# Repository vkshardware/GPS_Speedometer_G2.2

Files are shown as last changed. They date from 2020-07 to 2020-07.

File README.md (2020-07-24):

# GPS_Speedometer_G2.2
4-digits Speedometer (+ Odometer + Altimeter + Clock) for DIY all-terrain vehicles (ATV) with PULSE output

**vksensor GPS Speedometer G2.2**

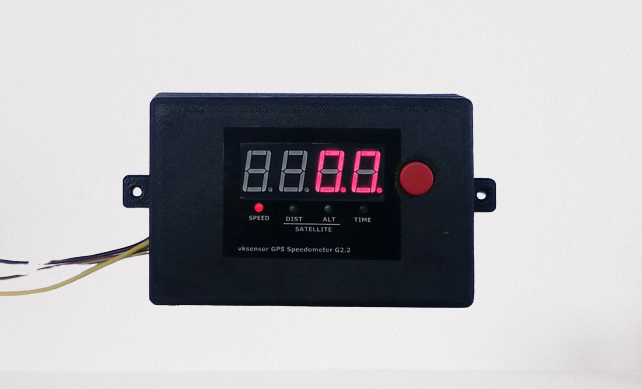
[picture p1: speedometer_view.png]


Speedometer is designed for DIY all-terrain vehicles (ATV). It has large bright 4-digit display (14 mm symbols) and
indicates speed, distance, altitude, satellite time. May be used as specific speed signal source for automotive
engines that uses ABS system sensors data (to compute vehicle speed).
Speedometer can transmit correct speed pulse to ABS block (replaces original ABS sensor). This fully tested with
engine Volkswagen Touran TDI 2.0 AZV (2004).

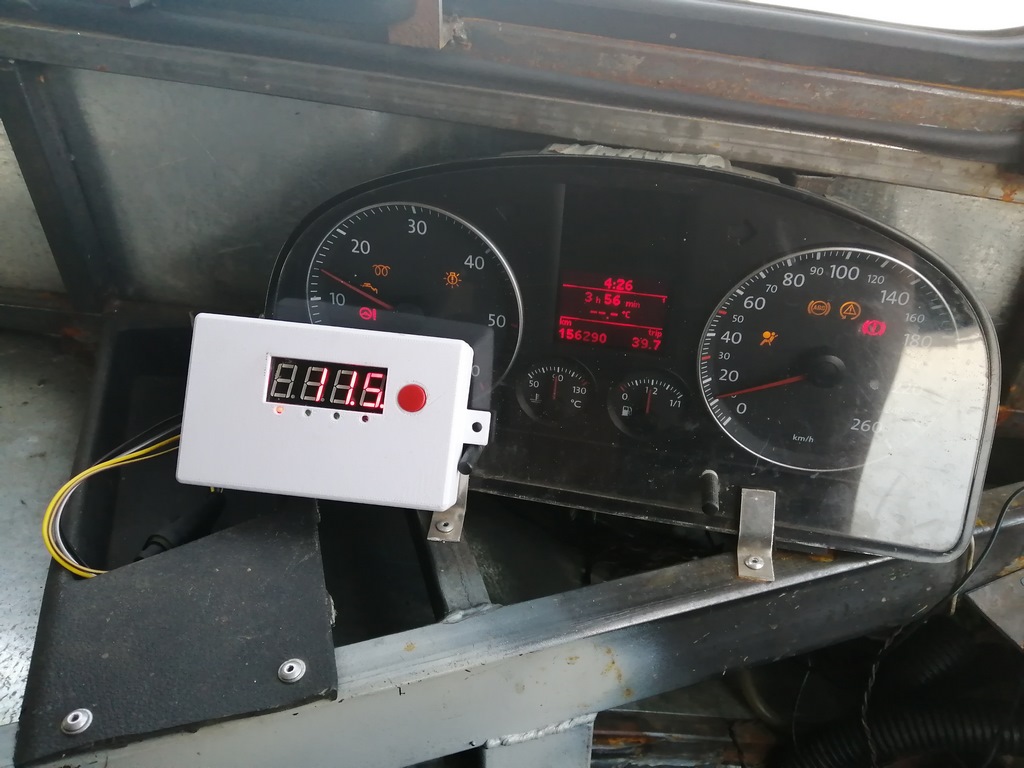
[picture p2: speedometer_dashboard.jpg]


If vehicle body shields GPS signal, you can connect active GPS antenna.

Speedometer uses Atmega324PA MCU with real-time GPS messages processing with GNSS GG1802 GPS receiver.

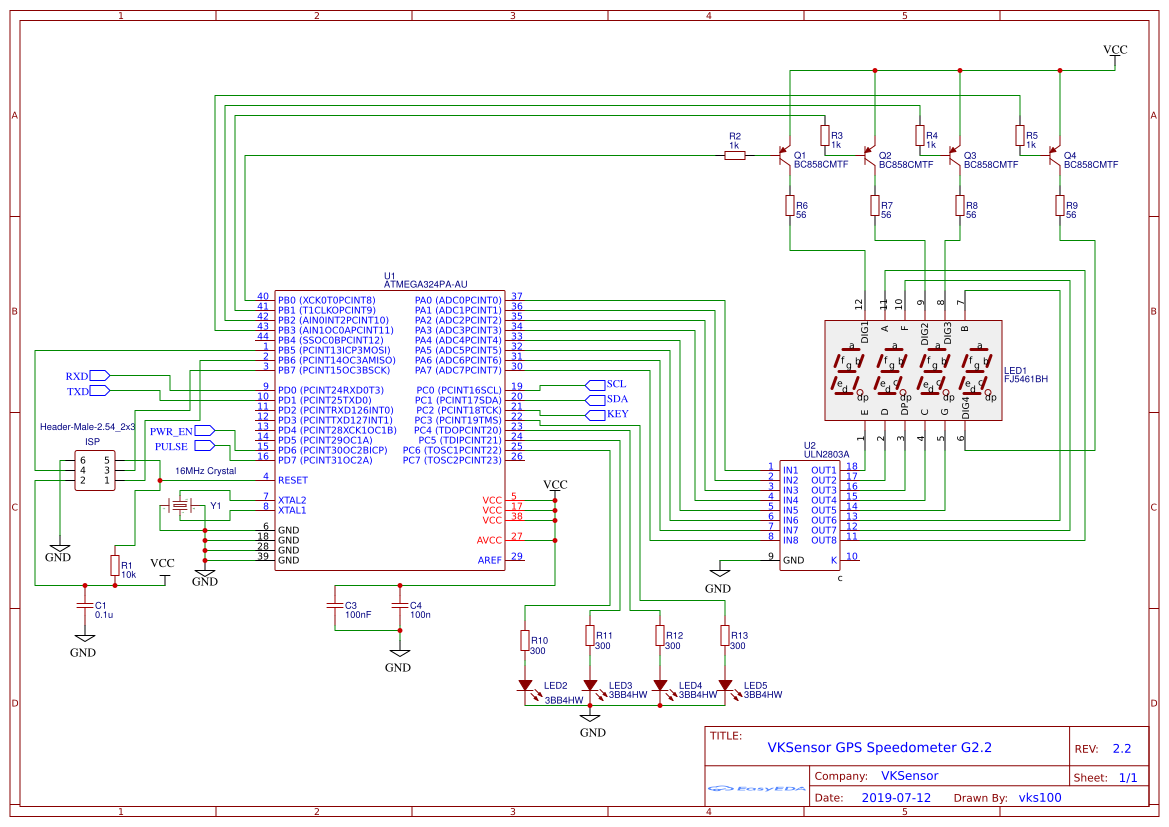
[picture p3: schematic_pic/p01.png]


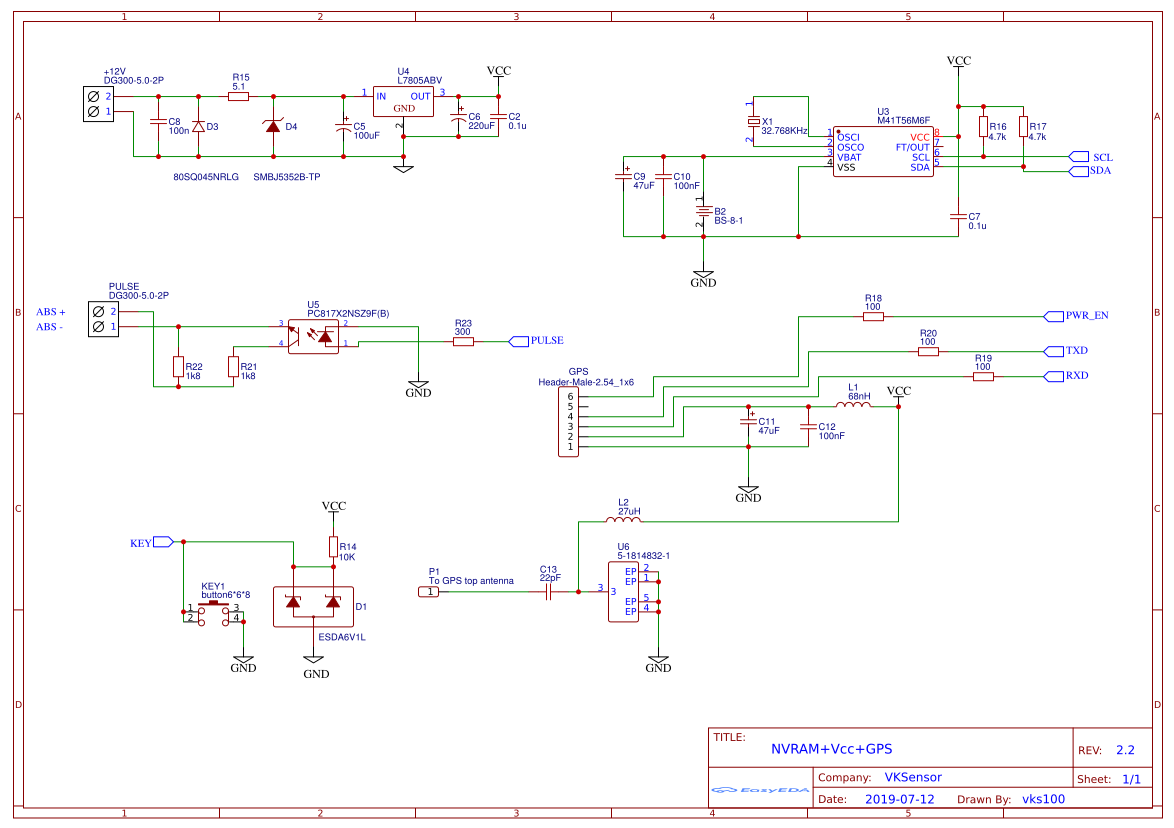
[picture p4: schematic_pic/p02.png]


All software and hardware designs are available here. 

****
**altimeter2_2_1** (dir) - C++ source code (Atmel Studio 7) 

**3d_case_model** (dir) - STL model for PLA plastic 3d printing

**ABS** (dir) - typical car ABS system connection schemes for Speedometer connection to ABS circuit

**photos_and_schemes** (dir) - Some Photos

**Schematic_GPS Speedometer G2.2.pdf** - Electrical Schemes

**Gerber_pcb_GPS_Speedometer G2.2.zip** - Gerber PCB files

**Manual G2.2_eng.pdf** - English manual

**Manual G2.2_ru.pdf** - Russian manual

****

Thank you for yours attention! Email me vkshardware@gmail.com if you have any questions.

2019 (c) by **vkshardware** GNU GPL Licensed

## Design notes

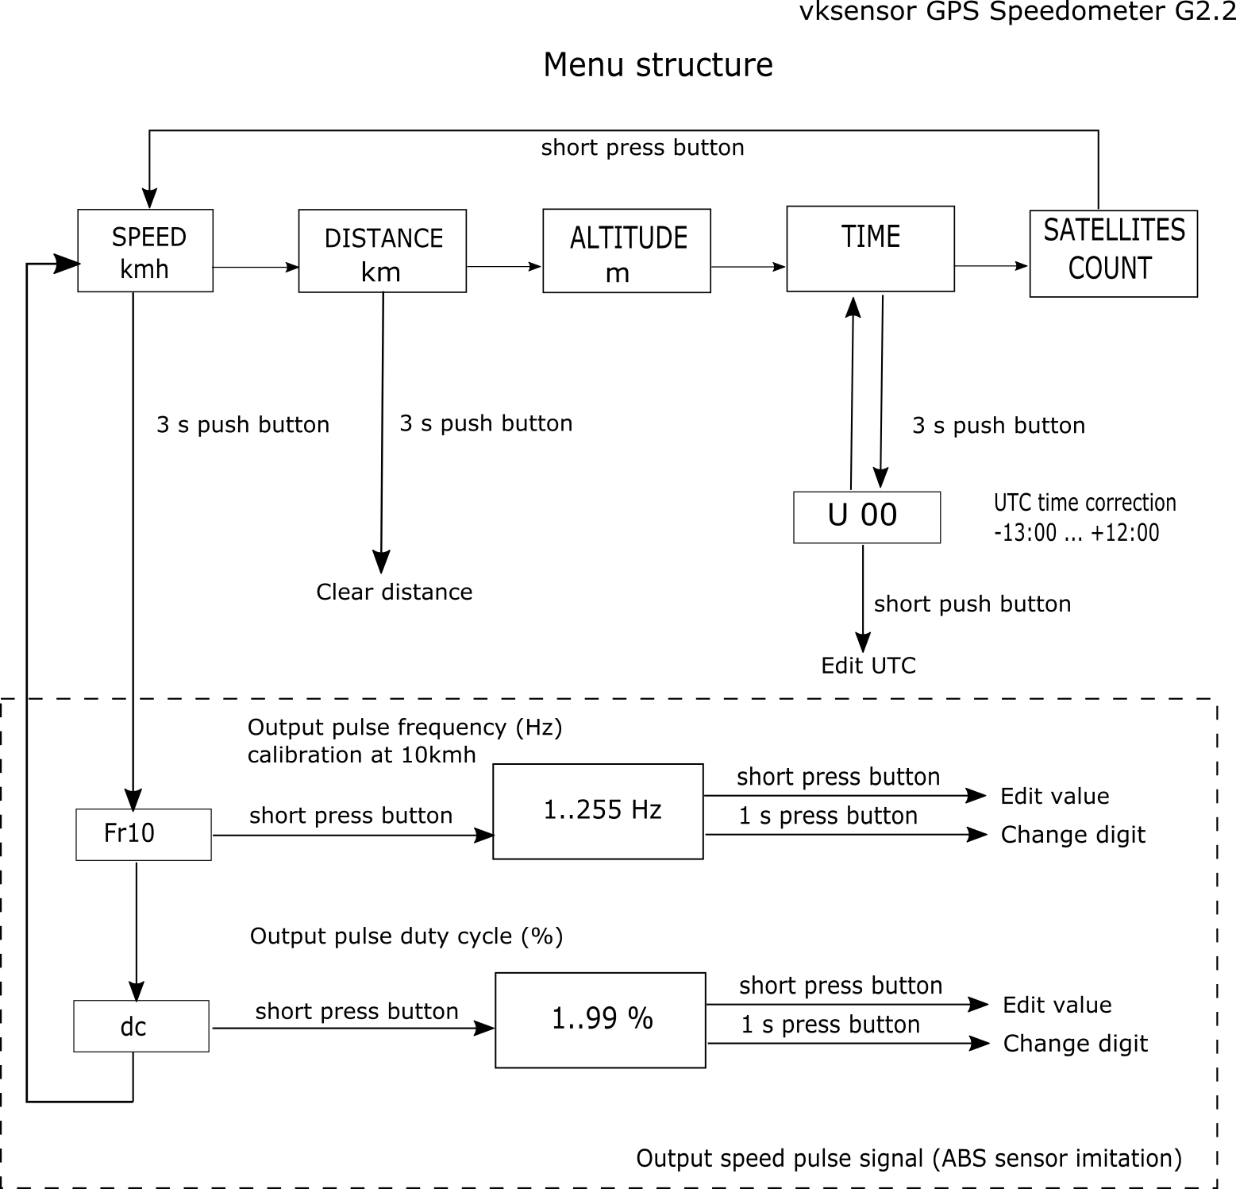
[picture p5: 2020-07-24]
photos_and_schemes/menu.svg.png

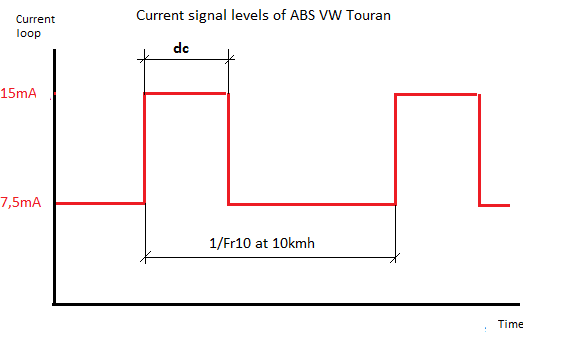
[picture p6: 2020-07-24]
photos_and_schemes/pulse.png

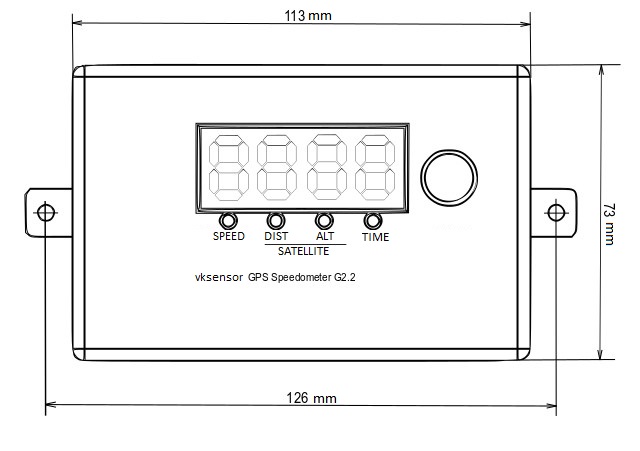
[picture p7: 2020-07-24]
photos_and_schemes/12_3_eng.jpg

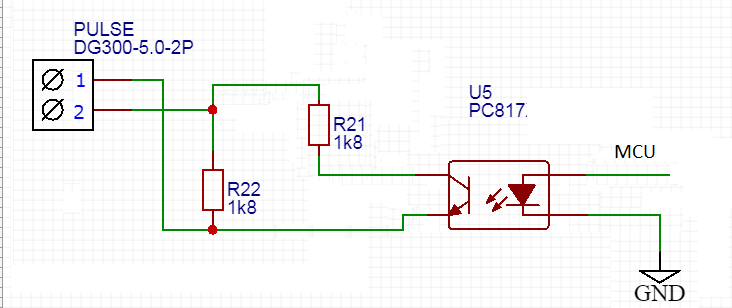
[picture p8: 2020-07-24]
photos_and_schemes/out_eng.png

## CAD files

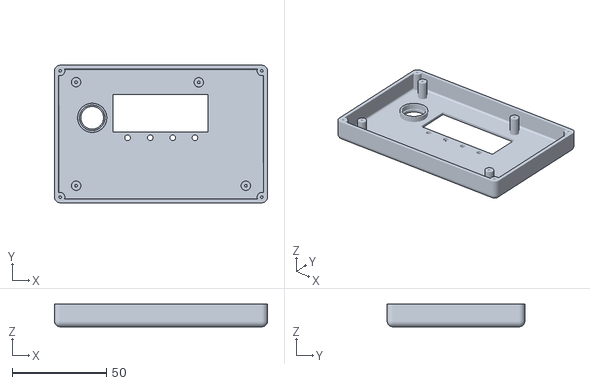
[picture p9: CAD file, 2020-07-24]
3d_case_model/box2_top.stl
113.0 x 73.0 x 12.0

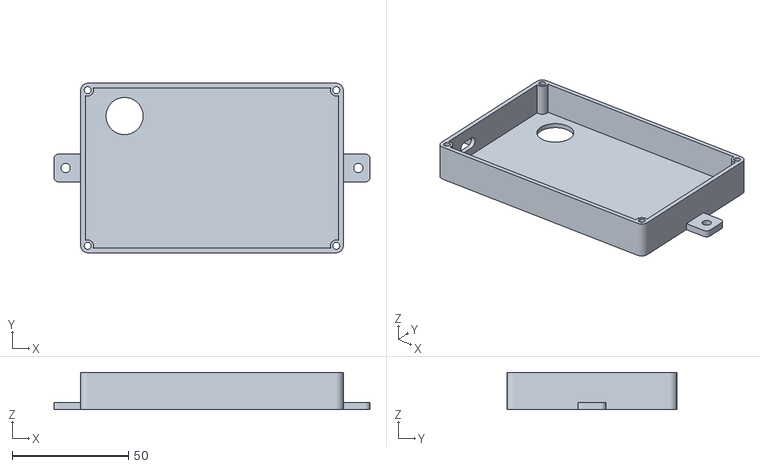
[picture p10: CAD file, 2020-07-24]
3d_case_model/box2_bottom.stl
136.0 x 73.0 x 16.0

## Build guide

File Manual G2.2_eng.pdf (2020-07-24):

Email: vkshardware@gmail.com

http://vksensor.ru

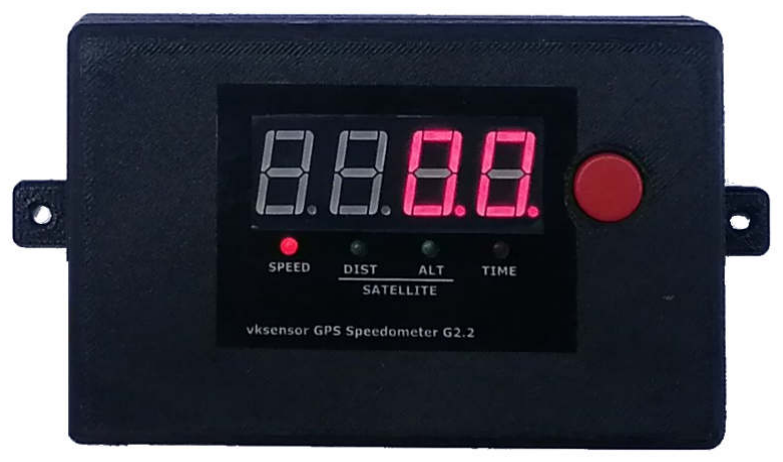
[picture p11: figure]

### Instruction Manual Rev 1.0

Speedometer is designed for DIY all-terrain vehicles (ATV). It has large bright 4-digit display (14 mm symbols) and indicates speed, distance, altitude, satellite time. May be used as specific speed signal source for automotive engines that uses ABS system sensors data (to compute vehicle speed).

Speedometer can transmit correct speed pulse to ABS block (replaces original ABS sensor). This fully tested with engine Volkswagen Touran TDI 2.0 AZV (2004).

If vehicle body shields GPS signal, you can connect active GPS antenna.

Technical characteristics

vksensor GPS Speedometer | G2.2
Power supply voltage | 12-15V
Power supply current | 0.15A
Dimensions | 113x73x28 mm
GPS receiver | GNSS GG1802
Display Modes:
1. Speed (km/h)
2. Distance counter (in km)
3. Altitude, (m)
4. GPS time (backed up with internal real-time clock)
5. Satellites count
Speed Accuracy | 0.1 km/h
Distance Accuracy | 0.1 km
Time zone (selectable) | -13 … +12 UTC
Tunable optocoupled pulse output (able to set pulse frequency and duty cycle)

Cold start time < 3 min
Hot start time < 5 s

Mileage data stored in NVRAM, which is powered by a CR2032 battery, battery life > 3 years.

External GPS antenna connector: SMA

After connecting the GPS power, the GG1802 receiver downloads satellite navigation data.

Speedometer displays “----“ symbols.

If the power off was more than 1 hour, the satellite search time is about 5 minutes. After a short power off (“hot start”), the search time is 3-30 s.

Navigation is possible if the number of visible satellites (menu "Satellites") is more than three.

Dimensions

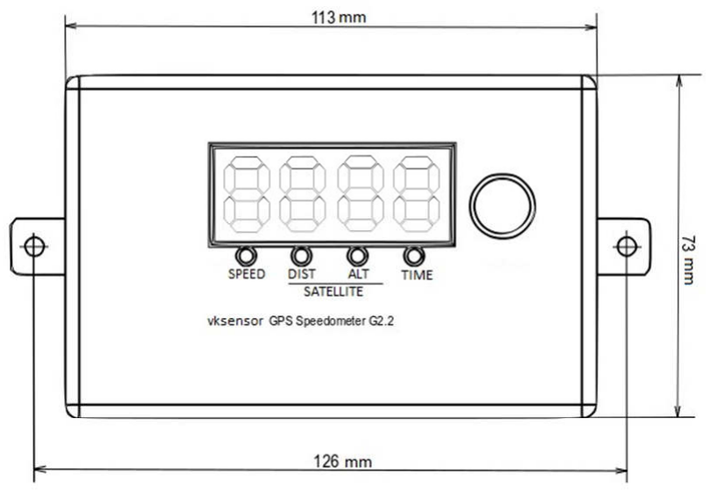
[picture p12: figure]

Connection diagram

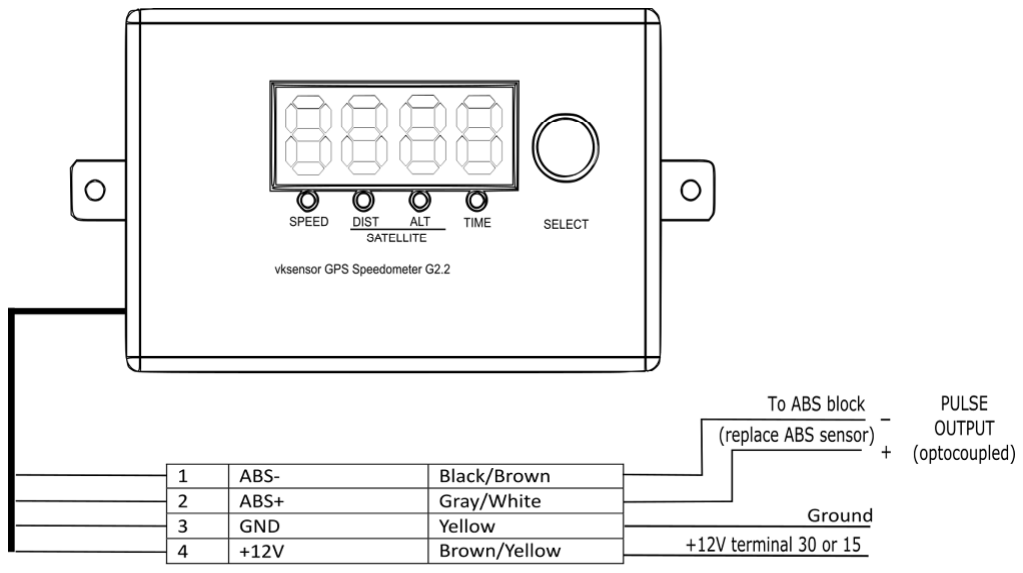
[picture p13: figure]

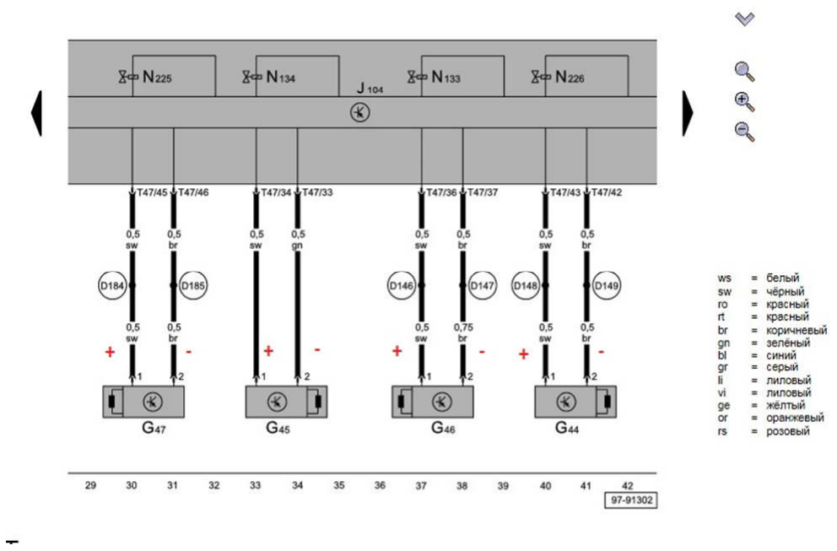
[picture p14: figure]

Example of automotive ABS sensors wiring (Volkswagen Touran TDI 2.0 AZV)

Speedometer replaces any one G4* sensor.

Setting the Speedometer

The transition between the five menus is carried out by briefly pressing the "Select" button.

1. Reset the odometer. To reset the current distance, go to the "DIST" menu and press and hold the "Select" button for more than 3 s.
2. Setting the Time Zone. It is made in the "TIME" menu. Automatic adjustment of the internal clock is carried out after downloading the latest satellite data. In order to set the UTC time zone, it is necessary to hold the “Select” button for about 3 s. The display will show “U 00”. Briefly pressing the "Select" button sets the time zone. Exit the setup menu and save by pressing the "Select" button for about 3 s.
3. The pulse output is configured in the “SPEED” menu
Long presses of the “Select” button (more than 3 s) go to the submenu:
1. "Fr10" - the number of pulses per second at a speed of 10 km/h.
2. "dc" - pulse duty cycle in %
3. Exit setup menu

By briefly pressing the button, you can enter the submenu. The setting is increased by short presses. You can transit between digits by pressing a button lasting about 1 s.
Saving and leaving the submenu is done by a long press of a button.

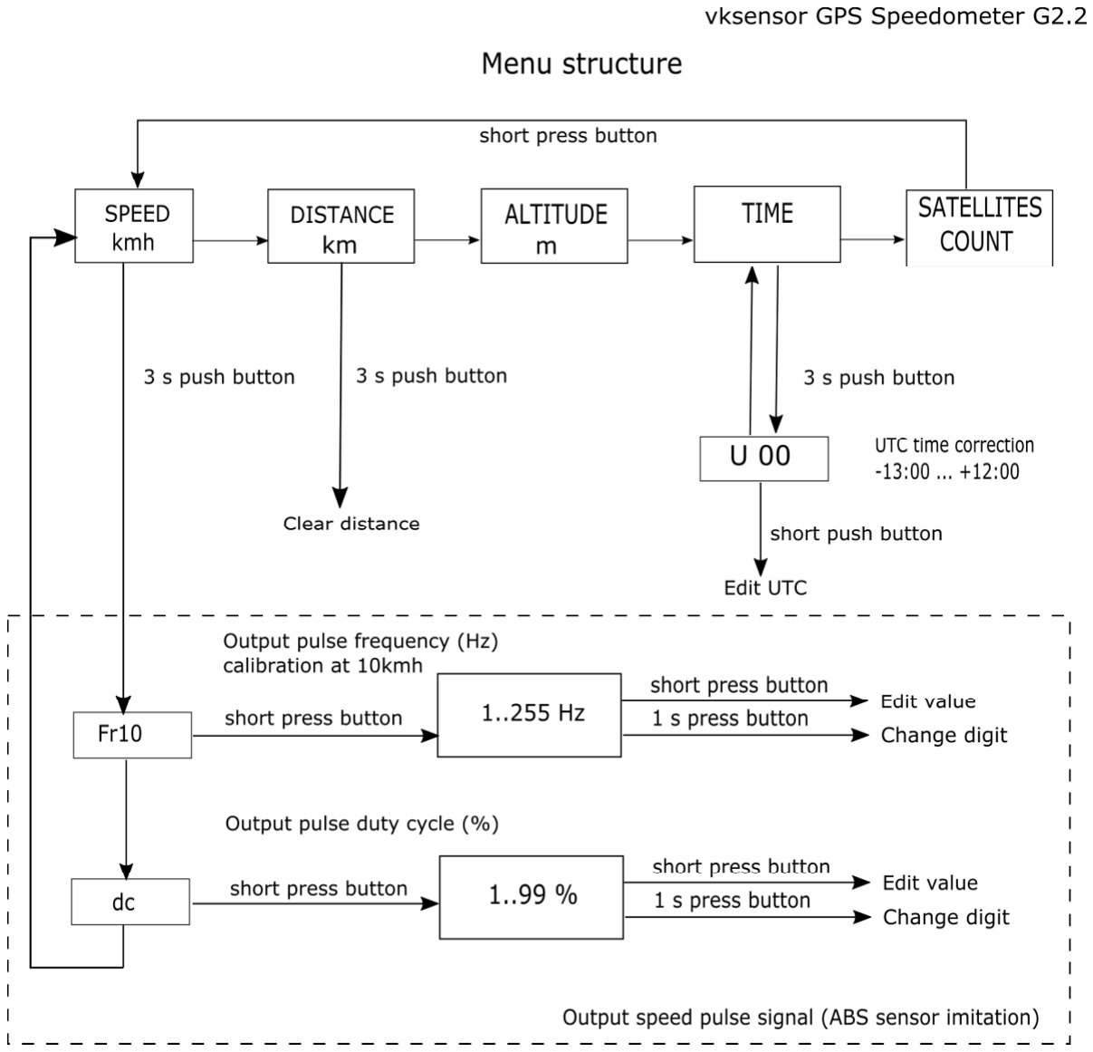
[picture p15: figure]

Parameter | Default setting (for VW Touran 1T1) | Minimal value | Maximal value
Pulse frequency Fr10, Hz | 65 | 1 | 255
Duty cycle, dc, % | 30 | 1 | 99

Pulse signal of ABS VAG

The speedometer can be used as a source of a pulse signal of speed for the ABS system of vehicle.

For cars of the VAG family, ABS sensors installed on the hubs are two-wire and have a current signal. The voltage on the ABS line is 12 V. The low level is 7.5 mA, high level is 15 mA. If other current levels are applied to the current loop, the ABS unit disconnects the sensor with the error “Invalid signal”. For the speed signal to work, it is enough to use any one (out of four) ABS sensor.

After connecting the sensor, it is necessary to reset the block errors in the ABS block with the diagnostic adapter (VAG COM, Vasya Diagnost, etc.). The ABS unit corresponds to the section "Electronics of the brake system"

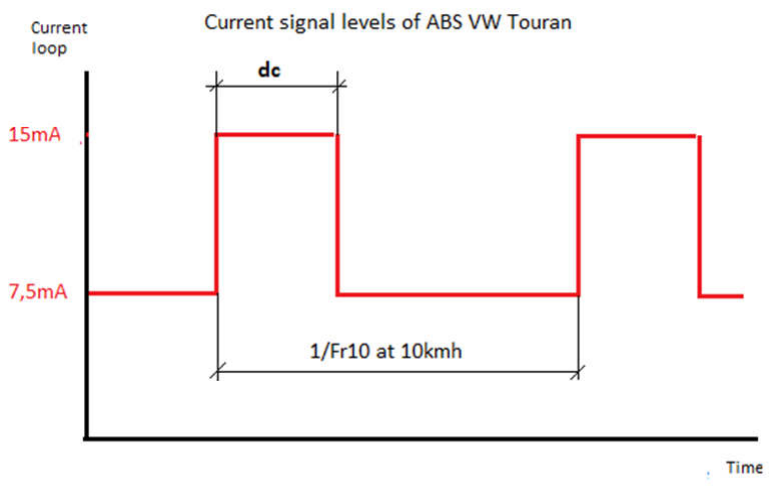
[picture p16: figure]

Note. For other types of active sensors, you may need to change values of resistors R21 and R22 on Speedometer PCB.

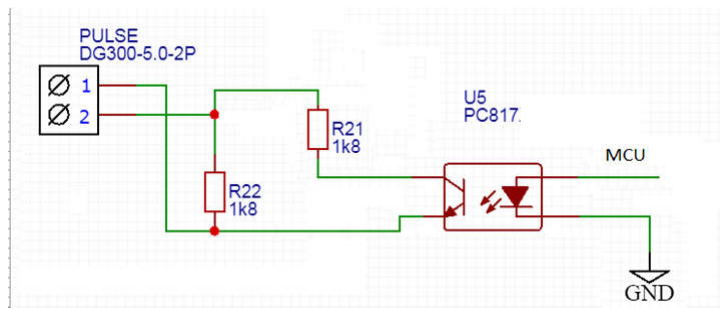
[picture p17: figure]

Speedometer Calibration

After entering the “Fr10” menu, pulses corresponding to a speed of 10 km/h appear on the pulse output.

Using the diagnostic adapter (for example, “Vasya Diagnostics” Russian analog VAG COM) go to the ABS block, section “Measured values”. Parameter group 001 will display speed data.

Select the speedometer parameter Fr10 so that the sensor readings correspond to 10 km / h. In this case, the speed reading on the dashboard should correspond to 10 km / h.

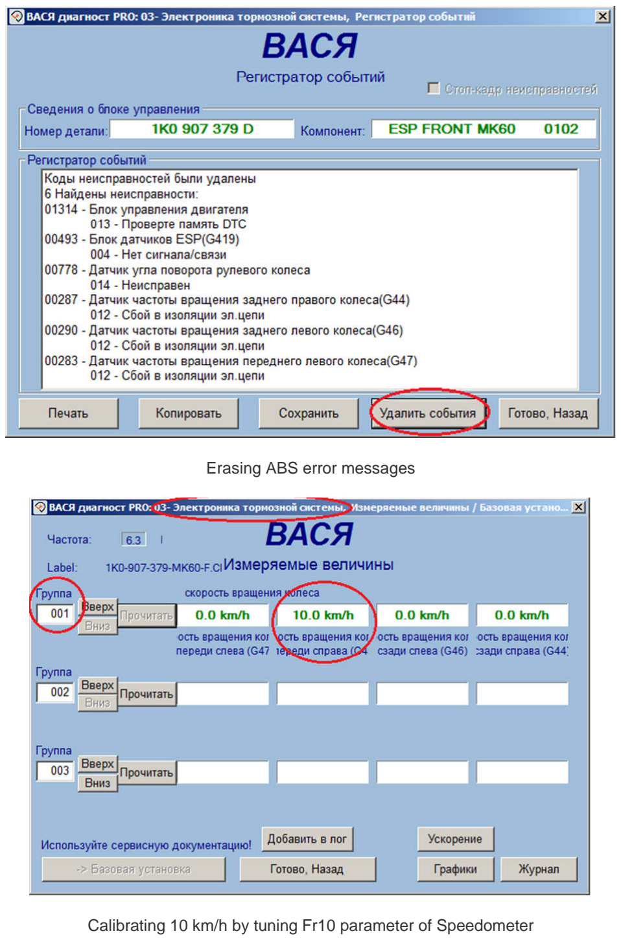
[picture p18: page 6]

Erasing ABS error messages

Calibrating 10 km/h by tuning Fr10 parameter of Speedometer

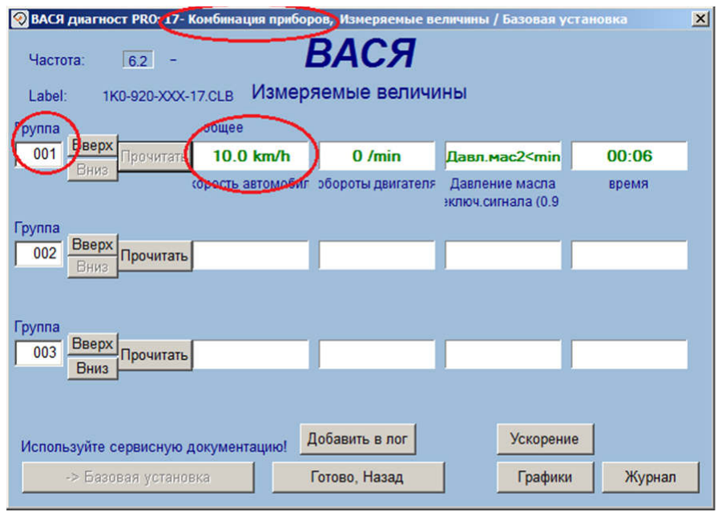
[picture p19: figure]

Checking parameters of speed in Dashboard block

Source code

Source code of Speedometer G2.2 is open.

Download and modify MCU source code (under GPL license):

http://vksensor.ru/load/0-0-0-20-20

Download schematics and PCB:

http://vksensor.ru/load/1

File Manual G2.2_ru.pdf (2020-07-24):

### GPS/ГЛОНАСС спидометр/одометр/высотомер/часы

### с возможностью подключения к ДВС

### VKSensor GPS Speedometer G2.2

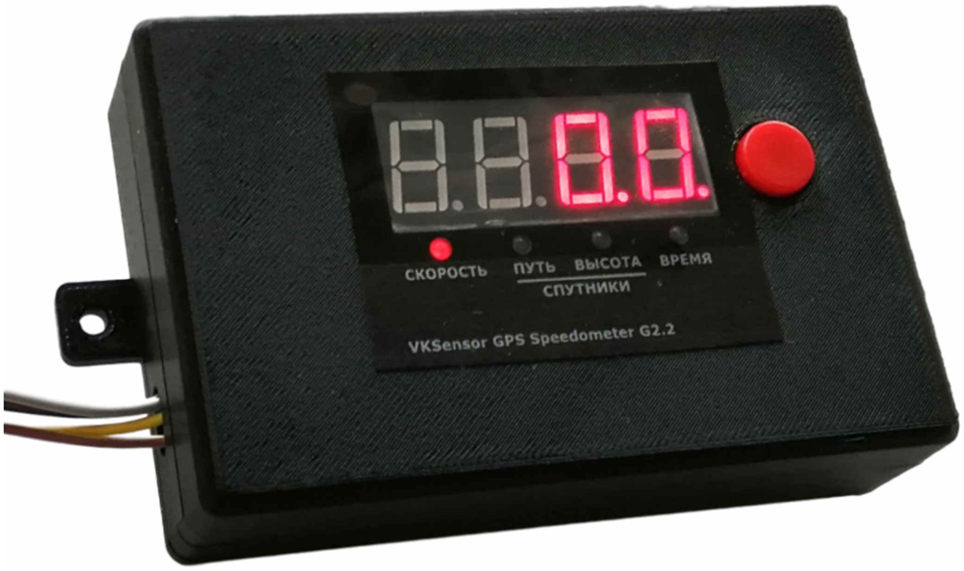
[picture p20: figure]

### Руководство по эксплуатации. Рев. 1.0/2019

2

### 1. Краткое описание

Данный спидометр предназначен для установки в вездеходы, мототехнику и другие транспортные средства. Значение скорости вычисляется на основании GPS/ГЛОНАСС спутниковых данных, получаемых встроенным приемником. Прибор имеет встроенную GPS антенну. В случае слабого сигнала внутри кабины ТС, имеется разъем для подключения активной GPS антенны.

Имеется пять режимов индикации:

### 1. Скорость 2. Пройденное расстояние 3. Высота над уровнем моря 4. Спутниковое время 5. Количество видимых спутников

Прибор имеет настраиваемый импульсный выход и позволяет подключать его в качестве датчика скорости к системе ABS современных автомобилей*. В этом случае данные скорости поступают в ЭБУ ДВС транспортного средства, двигатель «видит» реальную скорость движения и работает по оптимальным для него алгоритмам.

После отключения питания часы реального времени работают от литиевой батареи типа CR2032. Также батареей резервируются сохраненные данные о пробеге.

*Прибор протестирован как имитация активного датчика ABS Volkswagen 1T1

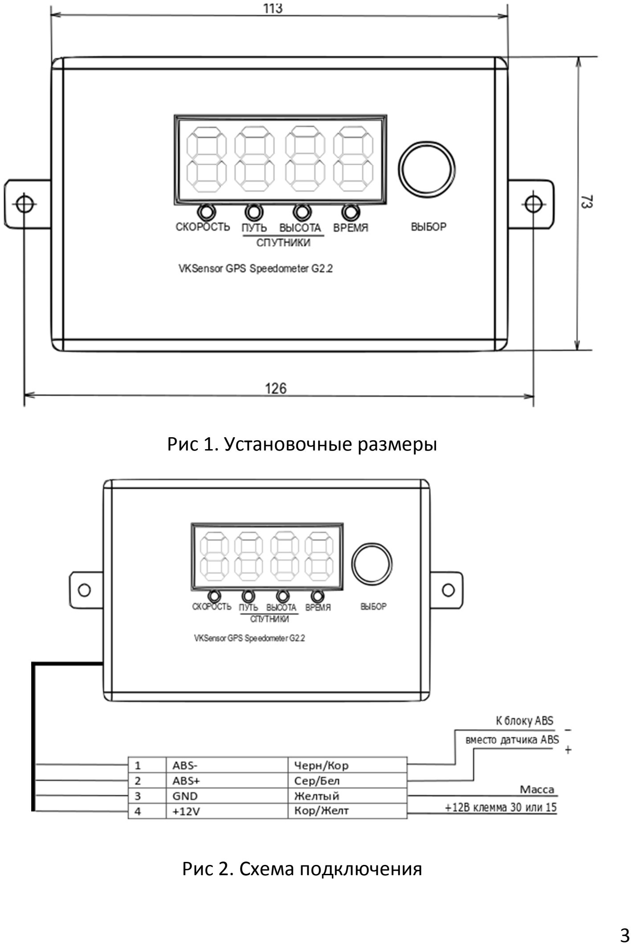
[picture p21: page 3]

3

Рис 1. Установочные размеры

Рис 2. Схема подключения

4

### 2. Технические характеристики

Модель | VKSensor GPS Speedometer G2.2
Тип принимаемых сигналов | GPS/ГЛОНАСС (до 12-ти спутников)
Напряжение питания | 12-15 В
Потребляемый ток | 0,15 А
Габаритные размеры | 113х73х28
Степень защиты | IP54
Рабочая температура | -25..+40°С
Точность измерения скорости | 0,1 км/ч
Точность измерения расстояния | 0,01 км
Часовой пояс UTC | -13:00 .. +12:00
Внешняя GPS антенна | SMA разъем
Импульсный выход ABS | Опторазвязанный, Uном=12В
Время холодного старта GPS приемника | < 3 мин
Время горячего старта GPS приемника | < 5 c
Батарея часов реального времени | CR2032, Li-ion, 3В
Время работы памяти от батареи | > 5 лет
Гарантийный срок службы | 1 год

### 3. Описание работы

После подключения питания GPS/ГЛОНАСС приемник осуществляет загрузку спутниковых навигационных данных. Если перерыв в питании составил более 1 часа («холодный старт»), то время поиска спутников составляет около 5 минут. После кратковременного отключения питания («горячий старт») время поиска 3-30 с.

Во время поиска спутников в меню «Скорость» и «Высота» отображается «- - - -» . Навигация возможна, если число видимых

5

спутников (меню «Спутники») более трех.
Переход между пятью меню осуществляется кратковременным нажатием кнопки «Выбор».

### 4. Настройка

### 1. Сброс одометра. Для сброса текущего расстояния

необходимо перейти в меню «Путь» и нажать удерживать кнопку «Выбор» более 3 с.

2. Настройка часового пояса. Производится в меню «Часы». Автоматическая подстройка внутренних часов осуществляется после загрузки актуальных спутниковых данных. Для того, чтобы настроить UTC часовой пояс, необходимо удерживать кнопку «Выбор» около 3 с. На дисплее будет отображаться «U 00». Кратковременным нажатием кнопки «Выбор» устанавливается часовой пояс. Выход из меню настройки и сохранение осуществляется нажатием кнопки «Выбор» около 3 с.

### 3. Настройка импульсного выхода производится в меню

«Скорость»

Длительными нажатиями кнопки «Выбор» (более 3 с) осуществляется переход в подменю:

3.1. «Fr10» - число импульсов в секунду на скорости 10 км/ч.
3.2. «dc» - скважность импульсов в %

### 3.3. Выход из меню настройки

Кратковременным нажатием кнопки можно зайти в подменю.

6

Табл. 1
Параметр | По умолчанию
для
VW Touran 1T1

Минимальная Максимальная

Частота
импульсов
Fr10 на
скорости
10км/ч, Гц
65 | 1 | 255

Скважность,
dc, %
30 | 1 | 99

Увеличение уставки осуществляется кратковременным нажатиями.
Переход между разрядами нажатием кнопки длительностью около 1,5 с. Сохранение и выход из подменю производится длительным нажатием кнопки.

### 6. Импульсный выходной сигнал ABS VAG

Спидометр можно использовать как источник импульсного сигнала скорости для системы ABS автомобиля. Данный спидометр протестирован для работы с активными токовыми датчиками ABS VW. У автомобилей семейства VAG датчики АВS, установленные на ступицах являются двухпроводными активными и имеют токовый сигнал.

Напряжение на линии АBS – 12 В.
Уровень лог. нуля 7,5 мА
Уровень лог. единицы 15 мА.

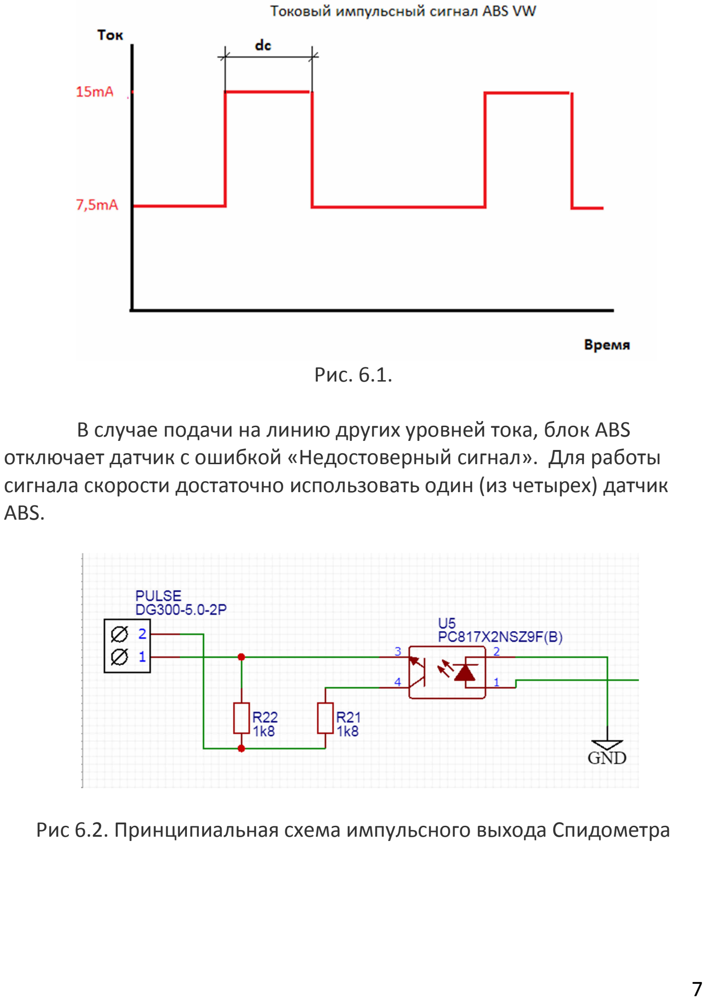
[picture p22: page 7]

7

Рис. 6.1.

В случае подачи на линию других уровней тока, блок ABS отключает датчик с ошибкой «Недостоверный сигнал». Для работы сигнала скорости достаточно использовать один (из четырех) датчик ABS.

Рис 6.2. Принципиальная схема импульсного выхода Спидометра

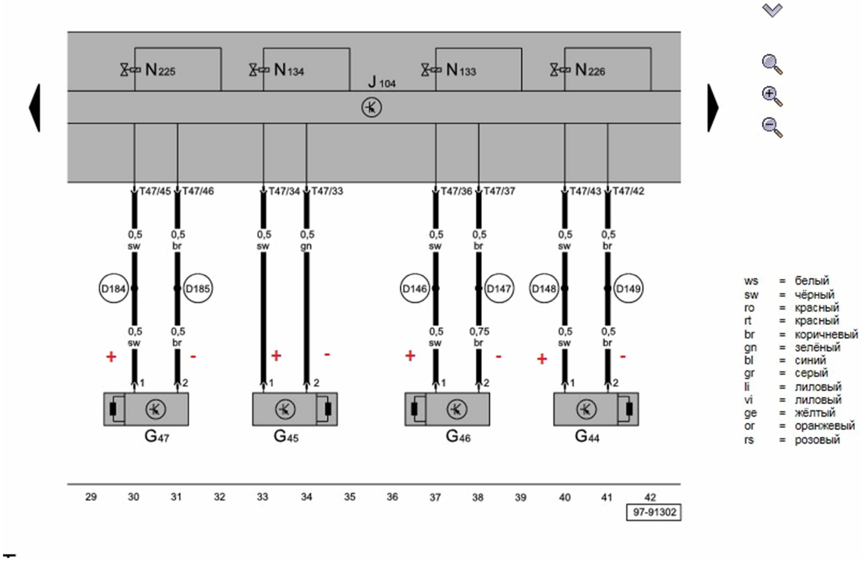
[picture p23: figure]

8

* Примечание. Для других типов активных датчиков, возможно, потребуется подобрать резисторы R21 и R22 (см. рис 6.2.). Для пассивных датчиков ABS может понадобиться согласующая схема.

Рис 6.3. Подключение датчиков ABS к блоку ABS на примере VW Touran 1T1 (ELSA). Спидометр подключается вместо любого датчика.

После подключения датчика, необходимо диагностическим адаптером (Вася Диагност, VAG COM и т.п.) в блоке ABS сбросить ошибки блока. Блок ABS соответствует разделу «Электроника тормозной системы» (рис 7.1, 7.3).

9

### 7. Калибровка Спидометра

После входа в меню Fr10, на импульсном выходе появляются импульсы, соответствующие скорости 10км/ч.

С помощью диагностического адаптера (для примера «Вася Диагност»), зайти в блок ABS, раздел «Измеряемые величины». В группе параметров 001 будут отображаться данные скорости (Рис 7.1 и 7.2).

Подобрать параметр Fr10 спидометра таким образом, чтобы показания соответствовали 10 км/ч. При этом показания скорости на приборной панели должны соответствовать 10 км/ч.

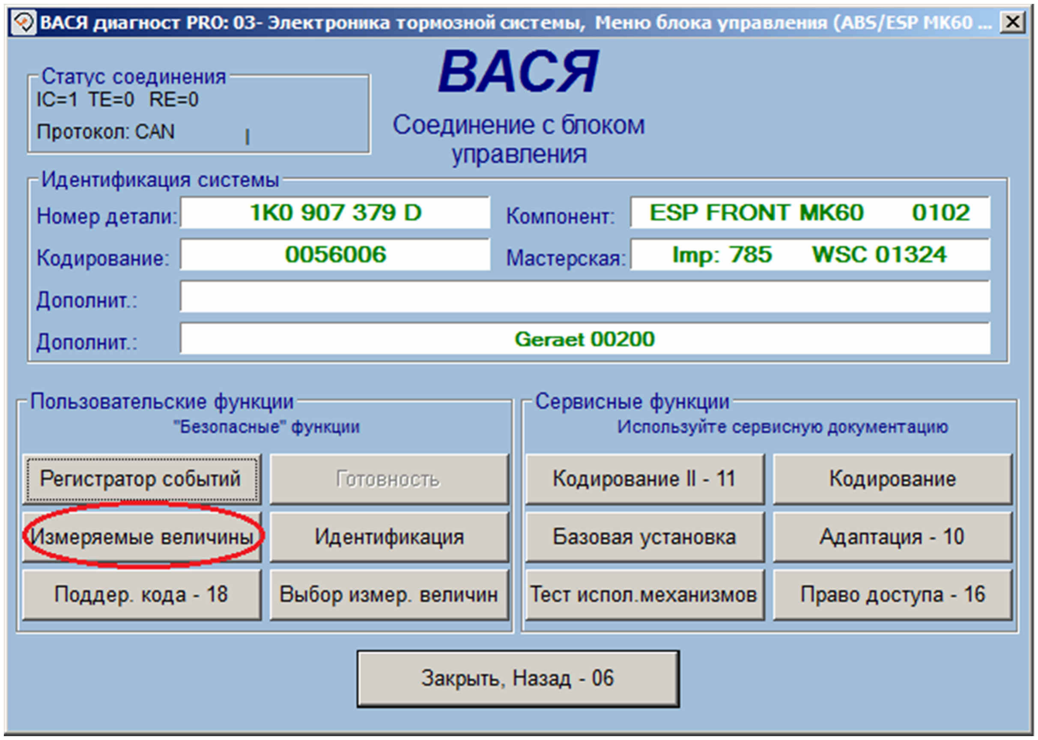
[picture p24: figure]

Рис 7.1. Раздел «Электроника тормозной системы»

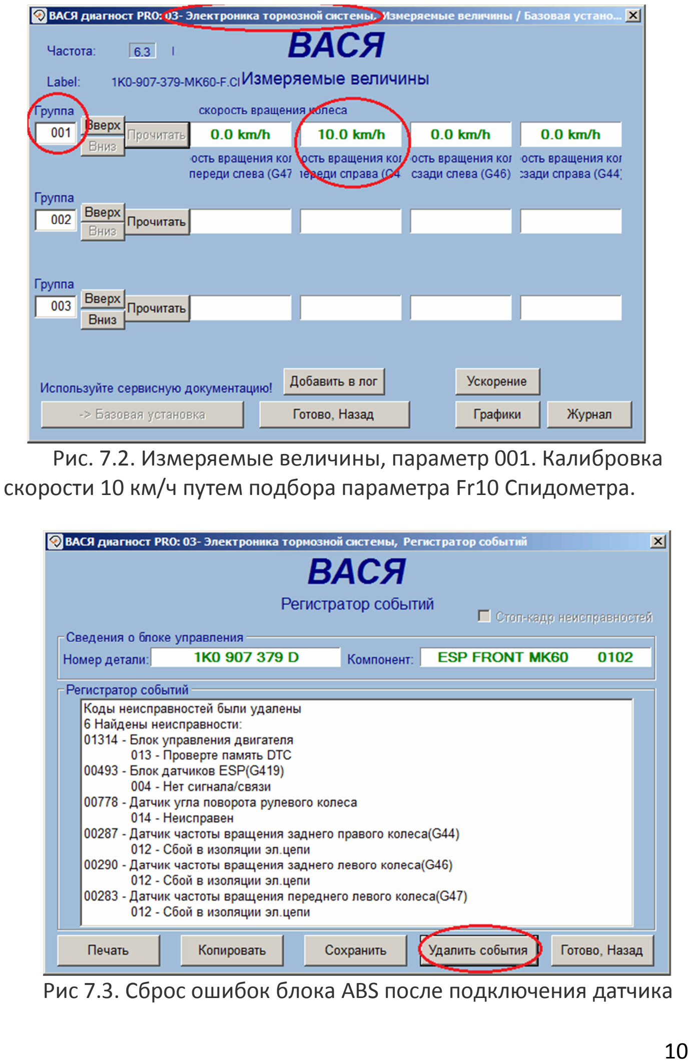
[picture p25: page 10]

10

Рис. 7.2. Измеряемые величины, параметр 001. Калибровка скорости 10 км/ч путем подбора параметра Fr10 Спидометра.

Рис 7.3. Сброс ошибок блока ABS после подключения датчика

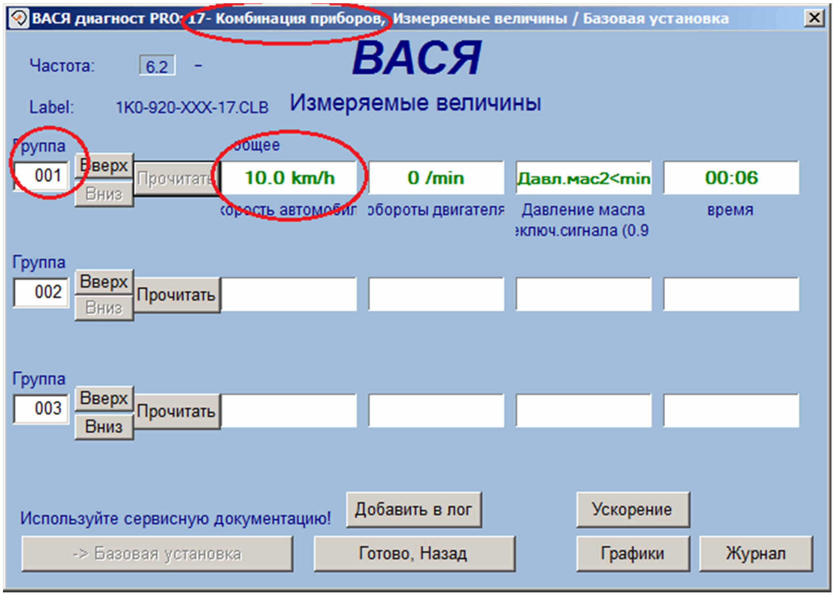
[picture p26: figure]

11

Рис 7.4. Раздел «Комбинация приборов», группа 001. Контроль значения скорости.

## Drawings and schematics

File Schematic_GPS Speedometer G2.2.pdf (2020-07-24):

## VCC

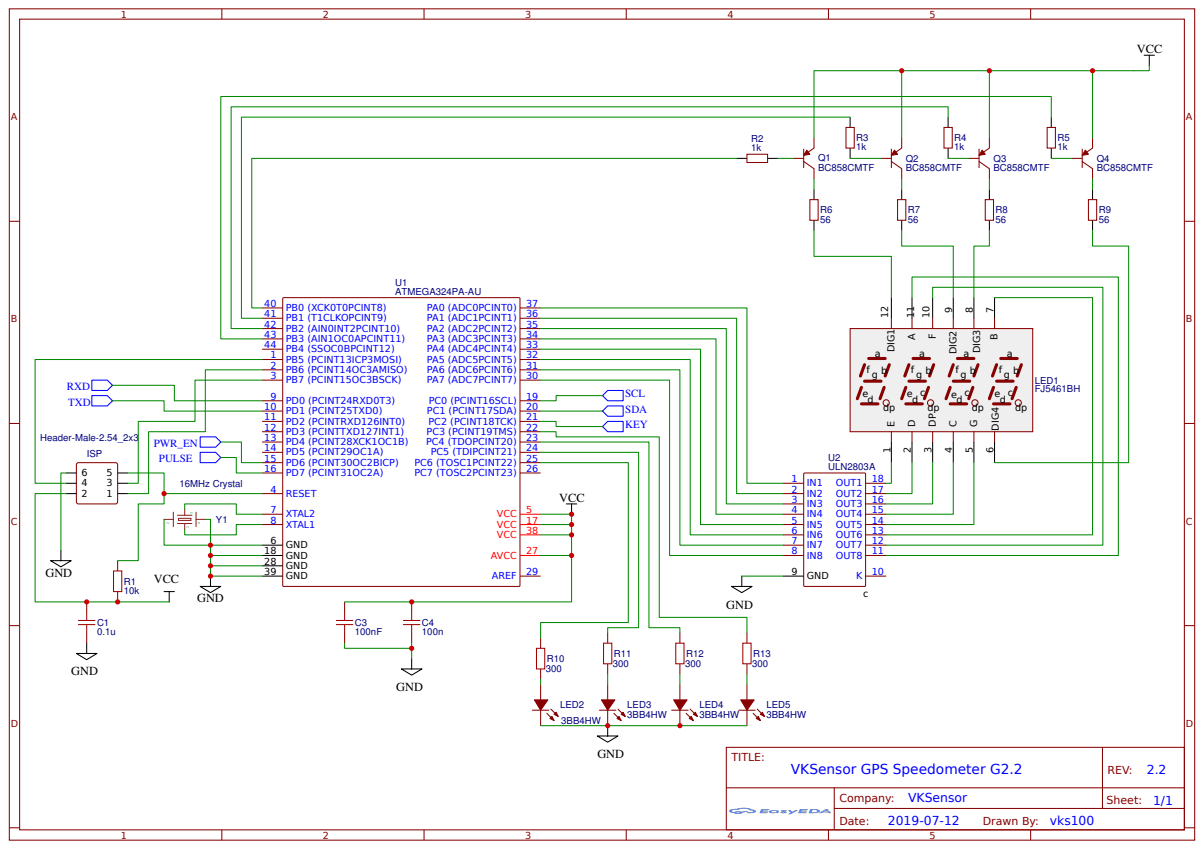
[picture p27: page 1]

## VCC

## VCC

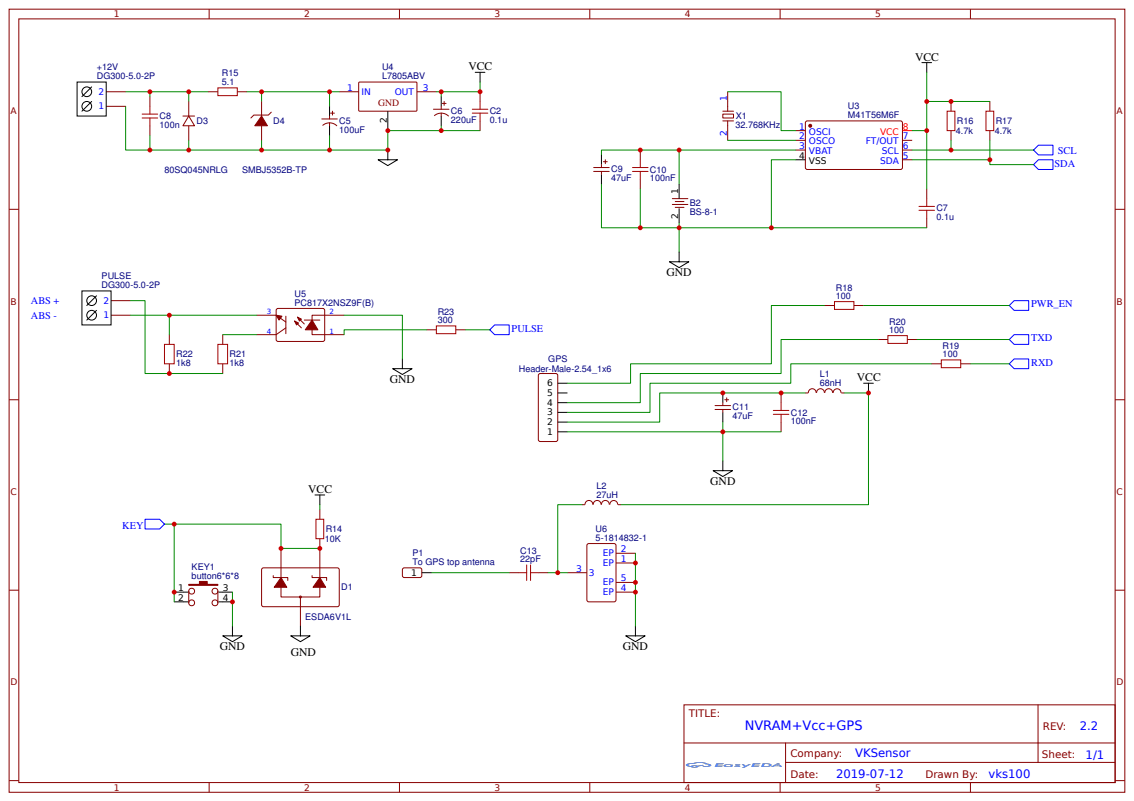
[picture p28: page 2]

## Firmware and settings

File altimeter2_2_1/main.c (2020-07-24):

	/*
	Hardware configuration Atmega324PA with four 7-segments led FJ5461BH in PCB layout
	
	Cathode a = pin30 = PA7;
	Cathode b = pin32 = PA5;
	Cathode c = pin34 = PA3;
	Cathode d = pin36 = PA1;
	Cathode e = pin37 = PA0;
	Cathode f = pin31 = PA6;
	Cathode g = pin33 = PA4;
	Cathode dp = pin32 = PA2;
	
	Anode 1 dig = pin40 = PB0;
	Anode 2 dig = pin41 = PB1;
	Anode 3 dig = pin42 = PB2;
	Anode 4 dig = pin43 = PB3;
	
	Leds configuration:
	
	LED2 = pin25 = PC6;
	LED3 = pin24 = PC5;
	LED4 = pin23 = PC4;
	LED5 = pin22 = PC3;
	
	Button:
	 
	KEY1 = pin21 = PC2;
	
	I2C NVRAM & real time clock M41T56
	
	SCL = pin19 = PC0
	SDA = pin20 = PC1
	
	GPS receiver GG1802 (USART0)
	
	RX0 = pin9
	TX0 = pin10
	
	*/
#define F_CPU                  16000000UL

#include <avr/io.h>
#include <util/delay.h>
#include <avr/interrupt.h>
#include <stdlib.h>
#include <math.h>
#include <avr/eeprom.h>
#include "twim.h"

#define  DIG1 1 << PB0
#define  DIG2 1 << PB1
#define  DIG3 1 << PB2
#define  DIG4 1 << PB3

#define SEG_A 1 << PA7
#define SEG_B 1 << PA5
#define SEG_C 1 << PA3
#define SEG_D 1 << PA1
#define SEG_E 1 << PA0
#define SEG_F 1 << PA6
#define SEG_G 1 << PA4
#define SEG_DP 1 << PA2

#define  LED2 1 << PC6  
#define  LED3 1 << PC5  
#define  LED4 1 << PC4  
#define  LED5 1 << PC3 


#define KEY1 1 << PC2    //  button
#define PULSE 1 << PD7    //  Pulse ABS output


#define KEY1_PUSH_DELAY 5
#define KEY1_LONGPUSH_DELAY 100
#define KEY1_MIDDLEPUSH_DELAY 50
#define KEY1_OFF_DELAY 5
#define UPDATE_DISPLAY 3
#define KPH_PER_NAUTICALMILE 1.852f  //knots to kph
#define PI 3.1415926f
#define MAX_DISTANCE 300.0f 
#define MIN_DISTANCE 13.0f
#define MIN_SPEED 3.2f
#define EARTH_RADIUS_METERS  6372795.0f
#define MAX_DUTYCYCLE 99
#define MIN_DUTYCYCLE 1
#define MAX_FREQ 255 
#define MIN_FREQ 1
#define TIMER1_CALIBRATION 0xC2F7 // 1 Hz timer 1024 divider
#define TIMER2_CALIBRATION 0xDA // 50kHz timer
#define DEFAULT_FREQ 65 //Hz for Volkswagen Touran 1T1 ABS 
#define DEFAULT_DC 30 // % negative duty cycle

#define M41T56_ADR    0b1101000 // Address for RTC/SRAM M41T56 in read mode 


union met
{
	unsigned long number;
	unsigned char bytes[4];
} Meters;


char buff0;
unsigned char buff1[8]="";
char actval[4] = "";

unsigned char Key1button, Key1_delay, CurrScreen = 0;
unsigned char Key1_store = 0;
unsigned char Key1_En = 1;
unsigned char RXwaitpause, GPS_Status = 0;
unsigned int GPS_Speed = 0;
unsigned int Distance = 0;
unsigned int GPS_Altitude = 0;
unsigned int GPS_Time, GPS_SatCount = 0;
unsigned char GPS_StatPointTimer = 0; 
unsigned char Timer1_en = 0;
unsigned char ReadSRAM = 1;
unsigned char UTC_Change, Fr10_Change, dc_Change = 0;
signed char UTC_TCorrection = 0;
float fLatitude,fLongitude, fPrevLatitude, fPrevLongitude = 0;
unsigned int Fr10_Pulse, dc_Pulse = 0;
unsigned char FirstScan = 0;
unsigned char SetPulseScreen, blink = 0;

char Time[12]=""; 
char Status[2]=""; 
char SLatitude[16]="";  
char NS[3]="";                          
char SLongitude[12]="";        
char EW[3]="";                  
char CourseTrue[10]="";         
char Data[12]="";               
char SatCount[4]="";            
char AltitudaMSL[12]="";        
char ViewSat[4]="";   
char COG[8]="";                 
char COGstat[4]="";             
char Speed[8]="";               
char SpeedAlt[8]="";    
char UNUSED[16]="";     
char Knot[8]="";
char Checksum[2] = "";
char *const RMC[]={Time,Status,SLatitude,NS,SLongitude,EW,Knot,CourseTrue,Data,UNUSED,UNUSED,UNUSED,UNUSED,UNUSED};
char *const GGA[]={UNUSED,UNUSED,UNUSED,UNUSED,UNUSED,UNUSED,SatCount,UNUSED,AltitudaMSL,UNUSED,UNUSED,UNUSED,UNUSED,UNUSED,UNUSED,UNUSED};
char *const GSV[]={UNUSED,UNUSED,ViewSat,UNUSED,UNUSED,UNUSED,UNUSED,UNUSED,UNUSED,UNUSED,UNUSED,UNUSED,UNUSED,UNUSED,UNUSED,UNUSED,UNUSED,UNUSED,UNUSED,UNUSED,UNUSED};

unsigned char GLONAS_COUNT=0;
unsigned char GPS_COUNT=0;
volatile char DataDone=0;
unsigned char DataValid=0;

uint16_t EEMEM fr10_eeprom;
uint16_t EEMEM dc_eeprom;

unsigned int Timer2_count, period, dc = 0;

void LoadEeprom(){
    Fr10_Pulse = eeprom_read_word(&fr10_eeprom);
    _delay_ms(5);
  
   if ((Fr10_Pulse > MAX_FREQ) || (Fr10_Pulse < MIN_FREQ)) 
   {
	   Fr10_Pulse = DEFAULT_FREQ;
	   eeprom_write_word(&fr10_eeprom,Fr10_Pulse);
	   _delay_ms(5);
   }
   
    
  dc_Pulse = eeprom_read_word(&dc_eeprom);
  _delay_ms(5);
  
   if ((dc_Pulse > MAX_DUTYCYCLE)||(dc_Pulse < MIN_DUTYCYCLE)) 
   {
	   dc_Pulse = DEFAULT_DC;
	   eeprom_write_word(&dc_eeprom,dc_Pulse);
	   _delay_ms(5);
   }
}

void WriteEeprom()
{
     eeprom_write_word(&fr10_eeprom,Fr10_Pulse);
	 _delay_ms(5);
	
	eeprom_write_word(&dc_eeprom,dc_Pulse);
	 _delay_ms(5);
}

void setled(unsigned char led)
{
	switch(led)
	{
		case 1: PORTC &= ~(LED3 | LED4 | LED5);
		PORTC |= (LED2);
		break;
		
		case 2: PORTC &= ~(LED2 | LED4 | LED5);
		PORTC |= (LED3);
		break;
		
		case 3: PORTC &= ~(LED2 | LED3 | LED5);
		PORTC |= (LED4);
		break;
		
		case 4: PORTC &= ~(LED2 | LED3 | LED4);
		PORTC |= (LED5);
		break;

		case 5:  PORTC &= ~(LED2 | LED5);
		PORTC |= (LED3 | LED4);
		break;
		
		default: PORTC |= (LED2 | LED3 | LED4 | LED5);
		
		
	}
}


void setseg(unsigned char seg)
{
	//clear segment
	
	PORTA &= (SEG_DP);
	
	switch(seg)
	{
		case 10: PORTA |= (SEG_G);
		break;
		
		case 0:  PORTA |= (SEG_F | SEG_E | SEG_D | SEG_C | SEG_B | SEG_A);
		break;
		case 1:  PORTA |= (SEG_B | SEG_C);
		break;
		case 2:  PORTA |= (SEG_A | SEG_B | SEG_G | SEG_E | SEG_D);
		break;
		case 3:  PORTA |= (SEG_A | SEG_B | SEG_G | SEG_C | SEG_D);
		break;
		case 4:  PORTA |= (SEG_F | SEG_G | SEG_B | SEG_C);
		break;
		case 5:  PORTA |= (SEG_A | SEG_F | SEG_G | SEG_C | SEG_D);
		break;
		case 6:  PORTA |= (SEG_A | SEG_F | SEG_G | SEG_E | SEG_D | SEG_C);
		break;
		case 7:  PORTA |= (SEG_A | SEG_B | SEG_C);
		break;
		case 8:  PORTA |= (SEG_A | SEG_B | SEG_C | SEG_D | SEG_E | SEG_F | SEG_G);
		break;
		case 9:  PORTA |= (SEG_A | SEG_B | SEG_C | SEG_D | SEG_F | SEG_G);
		break;
		
		default: //empty segment
		break;
	}
}

void selectseg(unsigned char selseg)
{
	//clear 7seg led anodes
	
	PORTB  |= DIG1 | DIG2 | DIG3 | DIG4;
	
	switch(selseg)
	{
		case 1: PORTB &= ~(DIG1);
		break;
		
		case 2: PORTB &= ~(DIG2);
		break;
		
		case 3: PORTB &= ~(DIG3);
		break;
		
		case 4: PORTB &= ~(DIG4);
		break;
		
		default:
		break;
	}
}


char CharToHex(char src)
{
	if ((src > 47) && (src < 58))  //this covers 0-9
	src -= 48;
	else if ((src > 64) && (src < 71)) // this covers A-F
	src -= 55;
	
	return src;
}

void Parser(unsigned char data)
{
	static unsigned char ByteCount=0xFF;
	static unsigned long MsgType;
	static char *MsgTxt=(char*)&MsgType;
	static unsigned char ComaPoint=0xFF;
	static unsigned char CharPoint=0;
	static unsigned char Checksum_en=0;
	static unsigned char Checksumcalc = 0;
	char tmp;
	
	
	if(data=='$'){
		ByteCount=0;
		ComaPoint=0xFF;
		MsgTxt=(char*)&MsgType; 
		return;
		} 
	
	
	if(ByteCount==0xFF) return;                                                                     
	ByteCount++;
	

	
	if(ByteCount<=1){
		Checksumcalc = data;
		return; 
	}
			
	
	if(data=='*')
	{
			MsgType=0;
			Checksum_en = 1;
			CharPoint = 0;
			return;
	}
	
	if (!Checksum_en) Checksumcalc ^= data;  // XOR all bytes between '?' and '*' symbols
	
	
	if((ByteCount<6) && (ByteCount>1))            //keep message header
	{
		*MsgTxt=data;   
		MsgTxt++;
		return;
	}



	if (Checksum_en)   
	{
		Checksum[CharPoint] = data;
		CharPoint++;
		
		if (CharPoint > 1)
		{
			Checksum_en = 0;
			//process
			tmp = CharToHex(Checksum[0])*16+CharToHex(Checksum[1]);  // load hex checksum value 
					
		//	if (tmp != Checksumcalc)  CurrScreen = 0; // print error message
			
		}
		
		return;
	}	
	

	
	switch(MsgType)
	{
		
		case    0x434D524E:                             //GNRMC
		if(data==',') 
		{
			ComaPoint++;     
			CharPoint=0;
			RMC[ComaPoint][0]=0;
			return;
		}
		
		
		RMC[ComaPoint][CharPoint++]=data;
		RMC[ComaPoint][CharPoint]=0;
		return;

        case    0x4147474E:                             //GNGGA
		
		if(data==',')  {
			ComaPoint++;    
			CharPoint=0;
			GGA[ComaPoint][0]=0;
			return;
		}
        

        GGA[ComaPoint][CharPoint++]=data;
        GGA[ComaPoint][CharPoint]=0;
        return;

        case    0x56534750:             //GPGSV
        if(data==',')  {
			
			ComaPoint++;    
			
			CharPoint=0;
			GSV[ComaPoint][0]=0;
			return;
		}
					
        GSV[ComaPoint][CharPoint++]=data;
        GSV[ComaPoint][CharPoint]=0; 
        
		return; 
		
		default:        
			ByteCount=0xFF; 
		    break; 
	} 

	ByteCount=0xFF;
}


ISR (TIMER0_OVF_vect)
{
	cli();
	

	if (!(PINC & KEY1))  // Pressing button SB1, set up antinoise timer
	{
	  if (Key1button < 0xFF) Key1button++; 	
	} else
	{
	  Key1button = 0;
	  Key1_En = 1;
	}
	if (Key1_delay > 0) Key1_delay--;
    
	RXwaitpause++;
	
	GPS_StatPointTimer++;
	
	TCNT0 = 0;
	
	sei();
}

ISR (TIMER1_OVF_vect) // 1 Hz Timer
{
   
   Meters.number += round(GPS_Speed/36.0f);
  
  if (Meters.number >= 1e7) Meters.number = 0;

  blink =!blink;
  
  Timer1_en++; 
  TCNT1 = TIMER1_CALIBRATION;   
}

ISR (TIMER2_OVF_vect)
{
	cli();
	TCNT2 = TIMER2_CALIBRATION;
	Timer2_count++;
	if ((Timer2_count == 0xFFFF) || (Timer2_count >= period)) Timer2_count = 0;
	
	
	if ((Timer2_count == 0) || (period == 0xFFFF))
	{
		PORTD |= (PULSE);
	}
	
	if ((Timer2_count == dc) && (dc != 0xFFFF))
	    PORTD &= ~(PULSE);
	sei();
}

ISR (USART0_RX_vect)
{
	cli(); 
    buff0 = UDR0;
	
	Parser(buff0); 
	
	RXwaitpause = 0;


	sei();
}

ISR(TWI_vect)	
{
	TWI_Process();
}


int init_UART(void)
{

	UBRR0H=0;    //  
	UBRR0L=102;   //  UBRR=f/(16*band)-1 f=16000000Ãö band=9600,
	UCSR0A = 0;
	UCSR0B = (1 << RXCIE0)|(1 << TXEN0)|(1 << RXEN0);   //  interrupt enable, transmitting and receiving enable
	UCSR0C = (1 << UCSZ00)|(1 << UCSZ01);   //  8-bit

    return 0;
} 


unsigned int TimeToInt(char *src, unsigned short src_size, signed char utc_time)
{
   unsigned int num=0;
   unsigned int utc;
   
   utc = abs(utc_time)*100;
   
   for(int i=0; i<src_size; i++)
   {   
	   if ((src[i]-0x30) >= 10) return 0;
	   
	   num=num*10 + src[i]-0x30;
   }
   
   if (utc_time >= 0)
       num +=  utc;
	else
	{
		if (num < utc)
			num += 2400-utc;
		else
	        num -= utc;
	}
  
   if ((num / 100) >= 24) num -= 2400;
   
   return num;
}


// 4 digit point - used as GPS status indication.
//Low level - no data, blink - invalid data (V status), high - valid data (A status)

void print_gpsstatuspoint(void)
{
    switch (GPS_Status)
	{
	case 'V':	if (GPS_StatPointTimer >=30) PORTA |= SEG_DP;
				break;
	case 'A':   PORTA |=(SEG_DP);
	            break;
	default:    PORTA &= ~(SEG_DP);
	            break;
	}
}

void select_U(void)
{
	//Print "U" symbol
	
	PORTA &= ~(SEG_A | SEG_G | SEG_DP);
	
	PORTA |= (SEG_F | SEG_E | SEG_D | SEG_C | SEG_B);
	
}

void select_S(void)
{
	//Print "S" symbol
	
	PORTA &= ~(SEG_B | SEG_E | SEG_DP);
	
	PORTA |= (SEG_A | SEG_C | SEG_D | SEG_F | SEG_G);
	
}

void select_P(void)
{
	//Print "P" symbol
	
	PORTA &= ~(SEG_C | SEG_D | SEG_DP);
	
	PORTA |= (SEG_A | SEG_B | SEG_E | SEG_F | SEG_G);
	
}

void select_F(void)
{
	//Print "F" symbol
	
	PORTA &= ~(SEG_B | SEG_C | SEG_D | SEG_DP);
	
	PORTA |= (SEG_A | SEG_E | SEG_F | SEG_G);
	
}


void select_E(void)
{
	//Print "E" symbol
	
	PORTA &= ~(SEG_B | SEG_C | SEG_DP);
	
	PORTA |= (SEG_A | SEG_D | SEG_E |SEG_F |SEG_G);
	
}

void select_d(void)
{
	//Print "d" symbol
	
	PORTA &= ~(SEG_A | SEG_F | SEG_DP);
	
	PORTA |= (SEG_B | SEG_C | SEG_D |SEG_E |SEG_G);
	
}

void select_c(void)
{
	//Print "c" symbol
	
	PORTA &= ~(SEG_A | SEG_B | SEG_C | SEG_F | SEG_DP);
	
	PORTA |= (SEG_D | SEG_E | SEG_G);
	
}

void select_r(void)
{
	//Print "r" symbol
	
	PORTA &= ~(SEG_A | SEG_F | SEG_B | SEG_C | SEG_D | SEG_DP);

	PORTA |= (SEG_E |SEG_G);
}

void select_minus(void)
{
	// Print "-" symbol
	
	PORTA &= ~(SEG_A | SEG_B | SEG_C | SEG_D | SEG_E | SEG_F | SEG_DP);

	PORTA |= (SEG_G);
	
}

void print_UTC(signed char val)
{
	unsigned char i = 0;
	
	actval[3] = abs(val % 10);
	actval[2] = abs((val/=10) % 10);
	
	selectseg(1);
	select_U();
	_delay_ms(UPDATE_DISPLAY);
	
	selectseg(2);
	
	if (UTC_TCorrection < 0) select_minus();
	else
	  selectseg(11);
	_delay_ms(UPDATE_DISPLAY);
	
	
	for(i=3;i<=4;i++)  {
			
		selectseg(i);
			
		PORTA &= ~(SEG_DP);
			
		if (i == 4) print_gpsstatuspoint();
			
			setseg(actval[i-1]);
			
			_delay_ms(UPDATE_DISPLAY);
	}
}

void print_decimal(unsigned int val, char point_pos,char blink_pos)
{
	unsigned char i,n = 0;
	
	actval[3] = val % 10;	
	actval[2] = (val/=10) % 10;
	actval[1] = (val/=10) % 10;
	actval[0] = (val/=10) % 10;
	
	if (!blink_pos)
	{
		
	  while ((n<3) && (actval[n] == 0)) n++;  //remove excess zeroes
	
	  if (4-point_pos < n) n = 4-point_pos;
	}
	
	for(i=n+1;i<=4;i++)  
	if (((blink_pos == (5-i)) && blink) || (blink_pos != (5-i)))
	{
	   
	   selectseg(i);      
	   
	   PORTA &= ~(SEG_DP);
	   	   
	   if (point_pos == 5-i)   PORTA |= (SEG_DP); 
	   
	   if (i == 4) print_gpsstatuspoint();
       setseg(actval[i-1]);
	   
	   
	   _delay_ms(UPDATE_DISPLAY);
	}	
	
}

void print_nodata(void)
{
	int i;
	
	for(i=1;i<=4;i++)  {
		selectseg(i);
		
		PORTA &= ~(SEG_DP);
		
		if (i == 4) print_gpsstatuspoint();
				
		setseg(10);
		_delay_ms(UPDATE_DISPLAY);
	}
	   
}

void print_SP10(void)
{
	selectseg(1);
	select_S();
	_delay_ms(UPDATE_DISPLAY);
	selectseg(2);
	select_P();
	_delay_ms(UPDATE_DISPLAY);
	selectseg(3);
	setseg(1);
	_delay_ms(UPDATE_DISPLAY);	
	selectseg(4);
	setseg(0);
	_delay_ms(UPDATE_DISPLAY);
}

void print_Fr10(void)
{
	selectseg(1);
	select_F();
	_delay_ms(UPDATE_DISPLAY);
	selectseg(2);
	select_r();
	_delay_ms(UPDATE_DISPLAY);
	selectseg(3);
	setseg(1);
	_delay_ms(UPDATE_DISPLAY);
	selectseg(4);
	setseg(0);
	_delay_ms(UPDATE_DISPLAY);
}

void print_dc(void)
{
	selectseg(1);
	select_d();
	_delay_ms(UPDATE_DISPLAY);
	selectseg(2);
	select_c();
	_delay_ms(UPDATE_DISPLAY);
}

void print_error(void)
{
	
	selectseg(1);
	select_E();
	_delay_ms(UPDATE_DISPLAY);
	
	selectseg(2);
	select_r();
	_delay_ms(UPDATE_DISPLAY);
	
	selectseg(3);
	select_r();
	_delay_ms(UPDATE_DISPLAY);
	
}

float radians(float src)
{
	
	return PI*src/180;
}

float DistanceBetween2Points( float Lat, float Lon, float prev_Lat, float prev_Lon)
{
	float dLat = radians(Lat - prev_Lat);
	float dLon = radians(Lon - prev_Lon);
	float a = sin(dLat / 2.0f) * sin(dLat / 2.0f) +	cos(radians(prev_Lat)) * cos(radians(Lat)) * sin(dLon / 2.0f) * sin(dLon / 2.0f);
	
	float d = 2.0f * atan2(sqrt(a), sqrt(1.0f - a));
	return d * EARTH_RADIUS_METERS;
}

int HexToInt(char src)
{
	int dec,units;
	
	dec = (src & 0xF0) >> 4;
	units = src & 0x0F;
	
	
	return dec*10+units;
}

char IntToHex(int src)
{
	int dec,units;
	
	dec = src / 10;
	units = src % 10;
	
	return (dec << 4) | units;
	
}

void CalculateABSPulse()
{
	
	if (GPS_Speed == 0)
	{
		   period = 0xFFFF;
		   dc=0xFFFF;
		   return;
	}
	if (Fr10_Pulse > 0)
	  period = round((float)5e6/(Fr10_Pulse*GPS_Speed));
	else
	  period = 0xFFFF; 
	
	dc = round((float)period*dc_Pulse*0.01);
}

uint16_t AddDigitPulse(uint16_t src, uint16_t digit)
{
	uint16_t digit_fact = 0;
	uint16_t result = 0;
	uint16_t pow_t = 0;
	
	if (digit == 0) digit = 1;
		
	pow_t = round(pow(10,digit-1));
		
	digit_fact =  (src / pow_t);
	digit_fact = digit_fact % 10;
	
	src -= digit_fact*pow_t;
	
	digit_fact++;
	
	if (digit_fact > 9) digit_fact = 0;
	
	
	result = src + digit_fact*pow_t;
	
	return result;
}


void CheckRangePulse()
{
	if (Fr10_Pulse > MAX_FREQ) Fr10_Pulse = MAX_FREQ;
	if (Fr10_Pulse < MIN_FREQ) Fr10_Pulse = MIN_FREQ;
	
	if (dc_Pulse > MAX_DUTYCYCLE) dc_Pulse = MAX_DUTYCYCLE;
	if (dc_Pulse < MIN_DUTYCYCLE) dc_Pulse = MIN_DUTYCYCLE;
}
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
